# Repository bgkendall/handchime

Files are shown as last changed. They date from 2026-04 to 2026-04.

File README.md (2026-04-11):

# HandSTaMp

## Bill of Materials

| Reference | Silkscreen | Part | Footprint | Purpose |
|---|---|---|---|---|
| C1, C2 | 1µF | 2 × 1µF ceramic capacitors  | 0603 | Decoupling capacitors for U3 |
| C3 | 4µ7F | 4.7µF ceramic capacitor | 0603 | Bulk decoupling capacitor for U1 |
| C4 | 100nF | 100nF ceramic capacitor | 0603 | Decoupling capacitor for U1 |
| C5 | 100nF | 100nF ceramic capacitor | 0603 | Unwanted reset prevention |
| D1 | D1 | PMEG2010EA Schottky diode | SOD-323 | Reverse current protection |
| D2, D3 | D2, D3 | 2 × 1N4148 diodes | SOD-123 | Matrix diodes for SW1/SW2 |
| F1 | F1 | 500mA fuse | 0603 | Current overload protection |
| J1 | J1 | HRO TYPE-C-31-M-12 USB port | | For the pluggings in of USB cables |
| R1, R2 | 1, 2 | 2 × 5.1kΩ resistors | 0603 | USB power negotiation (Rd) resistors |
| R3 | 5k1Ω – P | 5.1kΩ resistor | 0603 | OPTIONAL 5V pull-up for RGB data line¹ |
| R4 | 1万Ω | 10kΩ resistor | 0603 | Prevention of unwanted boot state |
| S1, S2 | *None* | 2 × MX-compatible switches  | MX plate² | Keys for row 0, columns 0/1; mountings for PCB |
| U1 | U1 | STM32C071GBU6 | UFQFPN-28 | ~~Braaaains!~~ Microcontroller |
| U2 | U2 | PRTR5V0U2X | SOT-143 | ESD protection |
| U3 | U3 | XC6206P332MR-G LDO | SOT-23-3  | 5V to 3.3V step-down for U1 |

##### Notes

 1. Remove/do not place R3 (“P”) if not using pin PB0 to drive RGB LEDs (e.g., as a regular matrix pin).
    Pin PB0 must be set to [open drain mode][open-drain].
 2. Three-pin “plate-mount” switches can be used as-is. To use five-pin “PCB-mount” switches,
    the two extra plastic alignment “pins” must be removed.

[open-drain]: https://docs.qmk.fm/drivers/ws2812#open-drain-circuit

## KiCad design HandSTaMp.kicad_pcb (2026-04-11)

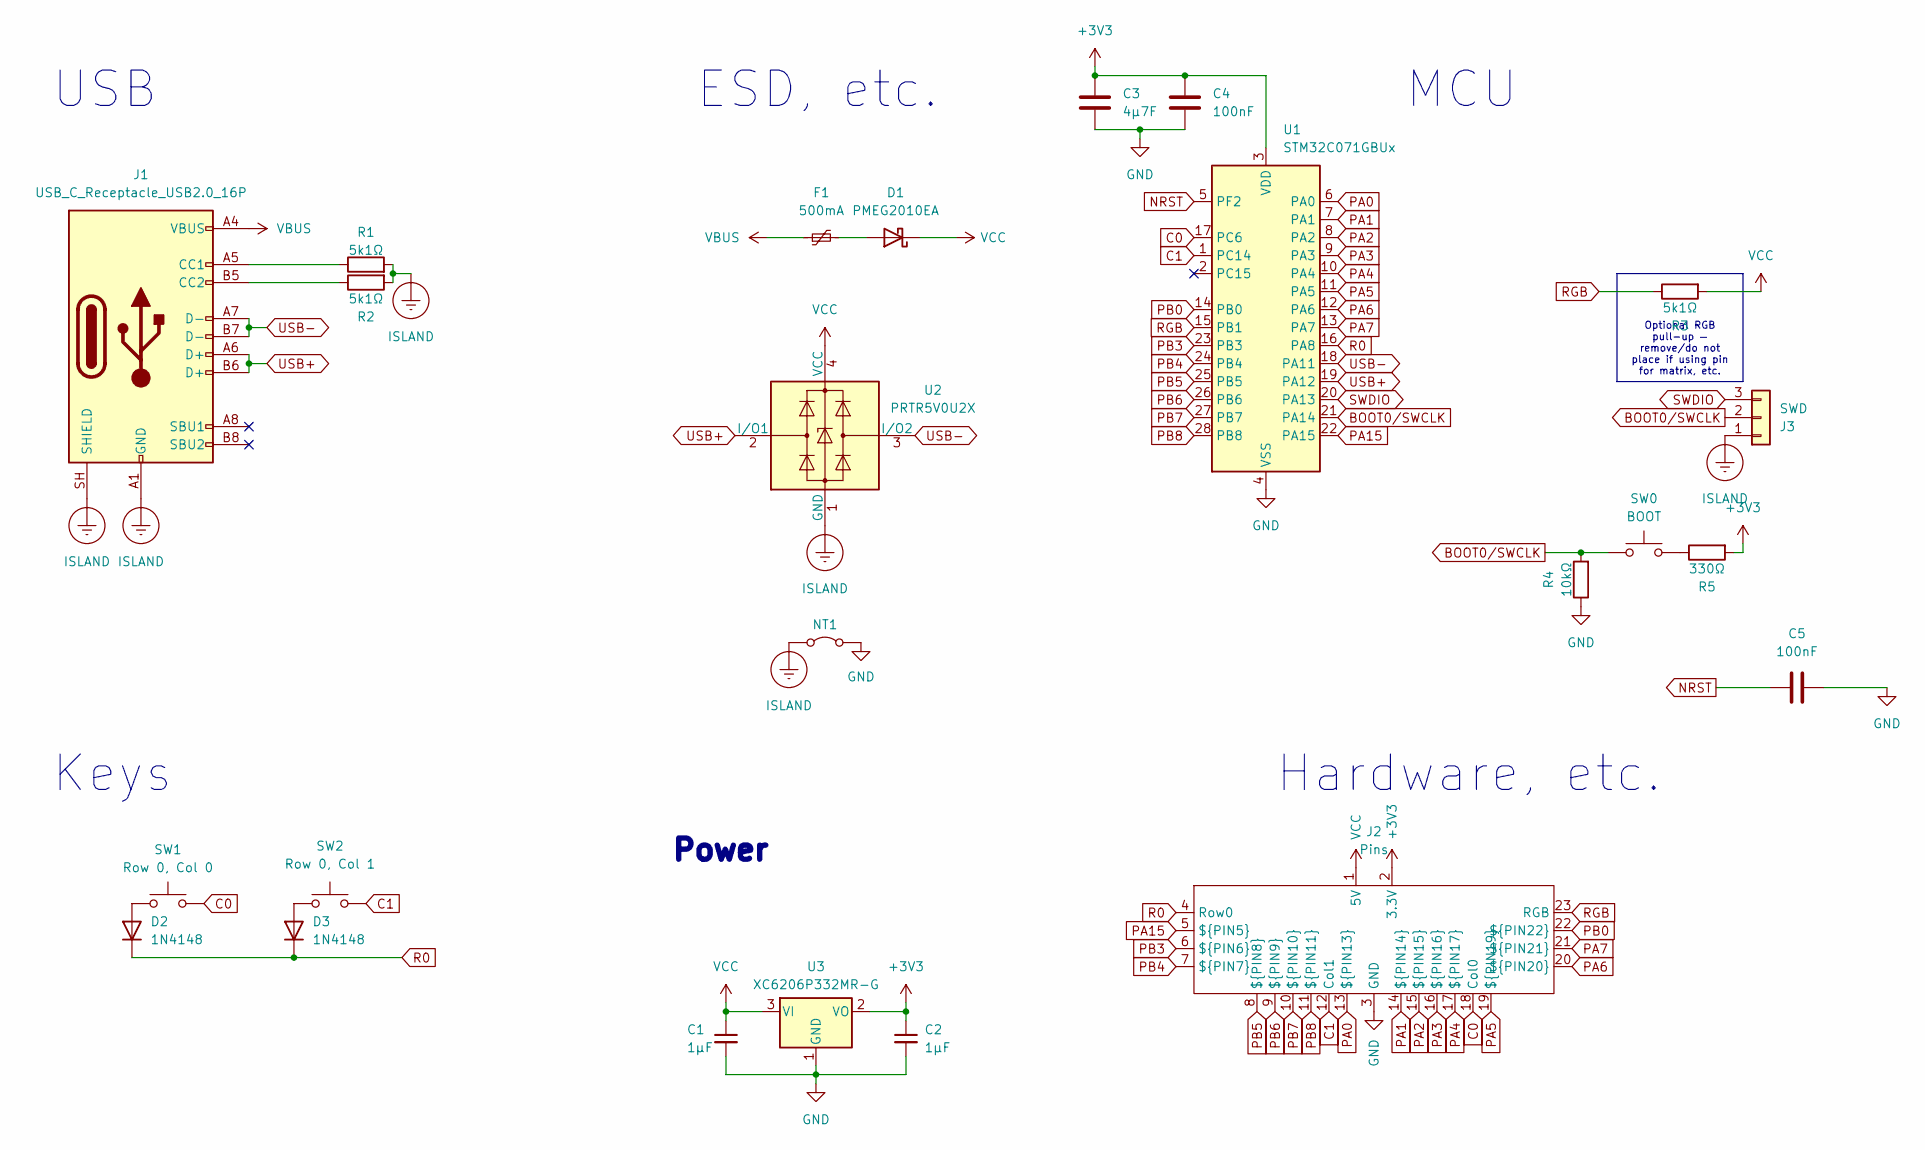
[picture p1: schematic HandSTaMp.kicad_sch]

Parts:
C1, C2: 1µF; C_0603_1608Metric; LCSC C52923
C3: 4µ7F; C_0603_1608Metric
C4, C5: 100nF; C_0603_1608Metric
D1: PMEG2010EA; D_SOD-323; LCSC C2837790
D2, D3: 1N4148; D_SOD-123
F1: 500mA; Fuse_0603_1608Metric; LCSC C210357
J1: USB_C_Receptacle_USB2.0_16P; USB_C_Receptacle_HRO_TYPE-C-31-M-12
J2: Pins; HandSTaMp
J3: SWD; SWD+GroundingPoint
NT1: Mounting Hole/Isolated Ground Jumper; NetTie-2_SMD_Pad0.5mm
R1, R2, R3: 5k1Ω; R_0603_1608Metric; LCSC C23186
R4: 10kΩ; R_0603_1608Metric; LCSC C23186
R5: 330Ω; R_0603_1608Metric; LCSC C23186
SW0: BOOT; SW_SPST_B3U-1000P; LCSC C231329
SW1: Row 0, Col 0; SW_MX_1u_PlateMount
SW2: Row 0, Col 1; SW_MX_1u_PlateMount
U1: STM32C071GBUx; QFN-28_4x4mm_P0.5mm
U2: PRTR5V0U2X; SOT-143; LCSC C12333
U3: XC6206P332MR-G; SOT-23-3

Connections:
+3V3: C2.1, C3.1, C4.1, J2.2 (3.3V), R5.2, U1.3 (VDD), U3.2 (VO)
BOOT0/SWCLK: J3.2, R4.2, SW0.1, U1.21 (PA14)
C0: J2.18 (Col0), SW1.1, U1.17 (PC6)
C1: J2.12 (Col1), SW2.1, U1.1 (PC14)
GND: C1.2, C2.2, C3.2, C4.2, C5.2, J2.3 (GND), NT1.2 (B), R4.1, U1.4 (VSS), U3.1 (GND)
ISLAND: J1.A1 (GND), J1.A12 (GND), J1.B1 (GND), J1.B12 (GND), J1.SH (SHIELD), J3.1, NT1.1 (A), R1.2, R2.2, U2.1 (GND)
NRST: C5.1, U1.5 (PF2)
unnamed: D1.2 (A), F1.2
unnamed: D2.2 (A), SW1.2
unnamed: D3.2 (A), SW2.2
unnamed: J1.A5 (CC1), R1.1
unnamed: J1.B5 (CC2), R2.1
unnamed: R5.1, SW0.2
PA0: J2.13 (${PIN13}), U1.6 (PA0)
PA1: J2.14 (${PIN14}), U1.7 (PA1)
PA2: J2.15 (${PIN15}), U1.8 (PA2)
PA3: J2.16 (${PIN16}), U1.9 (PA3)
PA4: J2.17 (${PIN17}), U1.10 (PA4)
PA5: J2.19 (${PIN19}), U1.11 (PA5)
PA6: J2.20 (${PIN20}), U1.12 (PA6)
PA7: J2.21 (${PIN21}), U1.13 (PA7)
PA15: J2.5 (${PIN5}), U1.22 (PA15)
PB0: J2.22 (${PIN22}), U1.14 (PB0)
PB3: J2.6 (${PIN6}), U1.23 (PB3)
PB4: J2.7 (${PIN7}), U1.24 (PB4)
PB5: J2.8 (${PIN8}), U1.25 (PB5)
PB6: J2.9 (${PIN9}), U1.26 (PB6)
PB7: J2.10 (${PIN10}), U1.27 (PB7)
PB8: J2.11 (${PIN11}), U1.28 (PB8)
R0: D2.1 (K), D3.1 (K), J2.4 (Row0), U1.16 (PA8)
RGB: J2.23 (RGB), R3.1, U1.15 (PB1)
SWDIO: J3.3, U1.20 (PA13)
USB+: J1.A6 (D+), J1.B6 (D+), U1.19 (PA12), U2.2 (I/O1)
USB-: J1.A7 (D-), J1.B7 (D-), U1.18 (PA11), U2.3 (I/O2)
VBUS: F1.1, J1.A4 (VBUS), J1.A9 (VBUS), J1.B4 (VBUS), J1.B9 (VBUS)
VCC: C1.1, D1.1 (K), J2.1 (5V), R3.2, U2.4 (VCC), U3.3 (VI)

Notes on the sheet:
Keys
MCU
Hardware, etc.
ESD, etc.
Power
USB
Optional RGB pull-up — remove/do not place if using pin for matrix, etc.

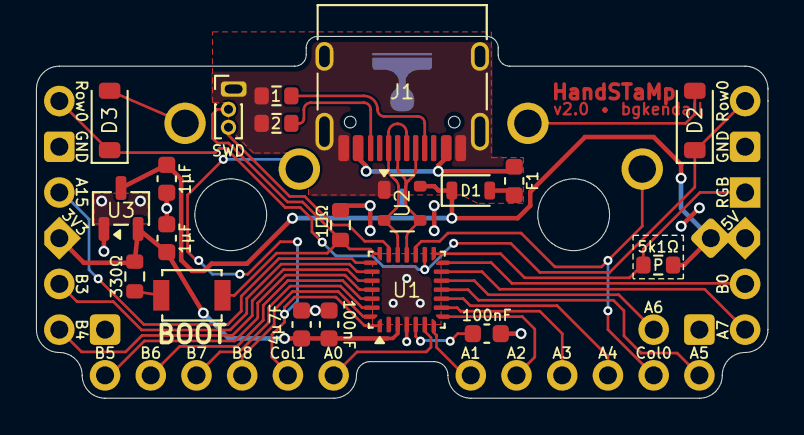
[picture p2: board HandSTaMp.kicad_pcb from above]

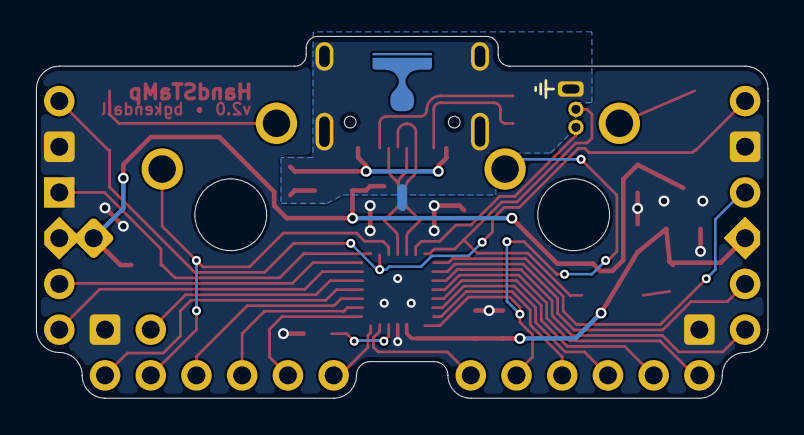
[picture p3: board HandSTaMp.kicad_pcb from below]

Board: 2 copper layers, 40.6 x 20.1 mm, 24 parts (3 on the bottom side), 36 nets.

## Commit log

2024-07-07 Add draft of HandCHime PCB
    [HandCHime.kicad_pcb, HandCHime.kicad_sch]
2024-07-07 Try moving MCU to central part of board
    [HandCHime.kicad_pcb, HandCHime.kicad_sch]
2024-07-09 Move MCU to centre of board and reroute
    [HandCHime.kicad_pcb, HandCHime.kicad_sch]
2024-07-09 Add logo
    [HandCHime.kicad_pcb]
2024-07-10 Straighten VCC track from MCU to pin
    Other routing tweaks
    [HandCHime.kicad_pcb]
2024-07-14 Use trace for 3V3, other routing tweaks
    [HandCHime.kicad_pcb]
2024-07-23 Add notches to bottom left and right corners
    This should avoid any supports that might be nearby between switches.
    [HandCHime.kicad_pcb]
2024-07-23 Correct CH552 schematic symbols
    [HandCHime.kicad_sch]
2024-07-23 Update net tie in schematic
    [HandCHime.kicad_pcb, HandCHime.kicad_sch]
2024-07-23 Move switches to centre of board
    [HandCHime.kicad_pcb]
2024-07-23 Add labels to pins
    Labels are currently on the back silkscreen, which is not the best. However, trying to squeeze them on the front seems optimistic.
    [HandCHime.kicad_pcb, HandCHime.kicad_sch]
2024-07-23 Move fuse away from newly lowered switch
    [HandCHime.kicad_pcb]
2025-01-25 Reduce default via size
    [HandCHime.kicad_pcb]
2025-01-25 Remove erroneous button
    [HandCHime.kicad_pcb]
2025-01-25 Update boot switch
    * Now uses the smaller B3U-1000P switch
    * Alternate pads provided on the keyswitch side so that Boot can be accessed by removing a keycap and poking through LED slot (on compatible switches)
    * Can now reroute C0 to avoid snaking around too much
    * Took advantage of now smaller vias on other traces
    [HandCHime.kicad_pcb, HandCHime.kicad_sch]
2025-01-25 Swap +5 and 3.3V outputs
    [HandCHime.kicad_pcb, HandCHime.kicad_sch]
2025-01-25 Fix part numbers for recently updated components
    [HandCHime.kicad_pcb, HandCHime.kicad_sch]
2025-01-25 Use smaller ESD chip
    USBLC6-2SC6 → PRTR5V0U2X
    [HandCHime.kicad_pcb, HandCHime.kicad_sch]
2025-02-13 Swap Row from P1.3 to P1.2 for better routing
    [HandCHime.kicad_pcb, HandCHime.kicad_sch]
2025-02-13 Minor tweaks
    * Round pads on boot button
    * Add back silkscreen for boot button
    * Improve pad size for Schottky diode (D1)
    * Tune VCC routing
    * Fix DRC errors on net ties
    * Fix board constraints to remove DRC errors on vias
    [HandCHime.kicad_pcb, HandCHime.kicad_sch]
2025-02-13 Move vias away from pin labels
    [HandCHime.kicad_pcb]
2025-02-13 Redo USB D± routing
    [HandCHime.kicad_pcb]
2025-12-12 Update KiCad version
2026-03-29 Update to KiCad v10
    [HandCHime.kicad_pcb, HandCHime.kicad_sch]
2026-03-29 Rename from HandCHime to Handchime
    With FAK development being discontinued, it no longer makes sense to use the **CH**552T. With an STM32, HandSTamp would make sense, but there are already a number of projects with “stamp”-based names. So the “Handchime” name stays, but without the emphasis on the “CH” part.
    [Handchime.kicad_pcb, Handchime.kicad_sch]
2026-03-29 Update schematic with STM32 version draft
    [Handchime.kicad_sch]
2026-03-30 Update breakout pin symbol and footprint
    [Handchime.kicad_sch]
2026-03-30 Update PCB with STH32 version draft
    [Handchime.kicad_pcb, Handchime.kicad_sch]
2026-03-30 Various tweaks and improvements
    [Handchime.kicad_pcb]
2026-03-30 Move USB port into required location
    [Handchime.kicad_pcb]
2026-03-30 Move board to align with MX grid
    [Handchime.kicad_pcb]
2026-03-30 Move components to work with relocated USB port
    [Handchime.kicad_pcb, Handchime.kicad_sch]
2026-03-30 Various tweaks
    [Handchime.kicad_pcb]
2026-03-31 Add 2-hole SWD access point
    [Handchime.kicad_pcb, Handchime.kicad_sch]
2026-03-31 Clean-up edge cuts, tidy routing around NRST
    [Handchime.kicad_pcb]
2026-03-31 Add RGB pull-up to edge pin 22
    PB0 has the following timers available for driving RGB LEDs using PWM:
    * TIM3_CH3
    * TIM1_CH2N
    [Handchime.kicad_pcb, Handchime.kicad_sch]
2026-03-31 Minor tweaks around U3
    [Handchime.kicad_pcb]
2026-03-31 Switch to two-layer stack-up
    [Handchime.kicad_pcb]
2026-03-31 Clean-up silkscreens, tweak routing
    [Handchime.kicad_pcb, Handchime.kicad_sch]
2026-04-02 Tweak component placement
    Tidy F1 and D1, and swap C3 and C3
    [Handchime.kicad_pcb]
2026-04-02 Fix edge pin alignment and improve silkscreen
    [Handchime.kicad_pcb, Handchime.kicad_sch]
2026-04-02 Use values instead of references for resistor and capacitor silkscreens
    [Handchime.kicad_pcb, Handchime.kicad_sch]
2026-04-02 Remove unused footprints from project library
2026-04-02 Add pad for shield ground connection to (metal) case
    [Handchime.kicad_pcb, Handchime.kicad_sch]
2026-04-02 Make grounding connection part of SWD access point
    [Handchime.kicad_pcb, Handchime.kicad_sch]
2026-04-02 Tweak routing
    [Handchime.kicad_pcb, Handchime.kicad_sch]
2026-04-02 Try to improve routing of Col1 trace
    [Handchime.kicad_pcb]
2026-04-04 Tweak edge of ground island fill
    [Handchime.kicad_pcb]
2026-04-07 Tweak routing and labelling of CC resistors
    [Handchime.kicad_pcb, Handchime.kicad_sch]
2026-04-07 Update labelling on optional RGB pull-op resistor
    [Handchime.kicad_pcb, Handchime.kicad_sch]
2026-04-07 Tweak NRST and adjacent routing
    [Handchime.kicad_pcb]
2026-04-07 Add draft BOM
2026-04-07 Fix resistor values in BOM
2026-04-08 Update outline of ground island; remove QR code
    The QR code was probably too small to be accurately silkscreened. The handchime logo has been moved to that location, and is now no longer blocked by the switches.
    [Handchime.kicad_pcb]
2026-04-08 Add one extra GPIO pin access
    [Handchime.kicad_pcb, Handchime.kicad_sch]
2026-04-08 Tweaked routing
    [Handchime.kicad_pcb]
2026-04-11 Increase middle inset by 5mil
    [Handchime.kicad_pcb]
2026-04-11 Change name to HandSTamp
    [Handchime.kicad_pcb, Handchime.kicad_sch]
2026-04-11 Update filenames and libraries
    [HandSTaMp.kicad_pcb, HandSTaMp.kicad_sch]
